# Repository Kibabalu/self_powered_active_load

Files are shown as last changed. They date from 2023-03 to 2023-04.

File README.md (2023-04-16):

# self_powered_active_load

Self powered active load based on the legendary LM10 Operational Amplifier and Voltage Reference IC originally designed by Bob Widlar.

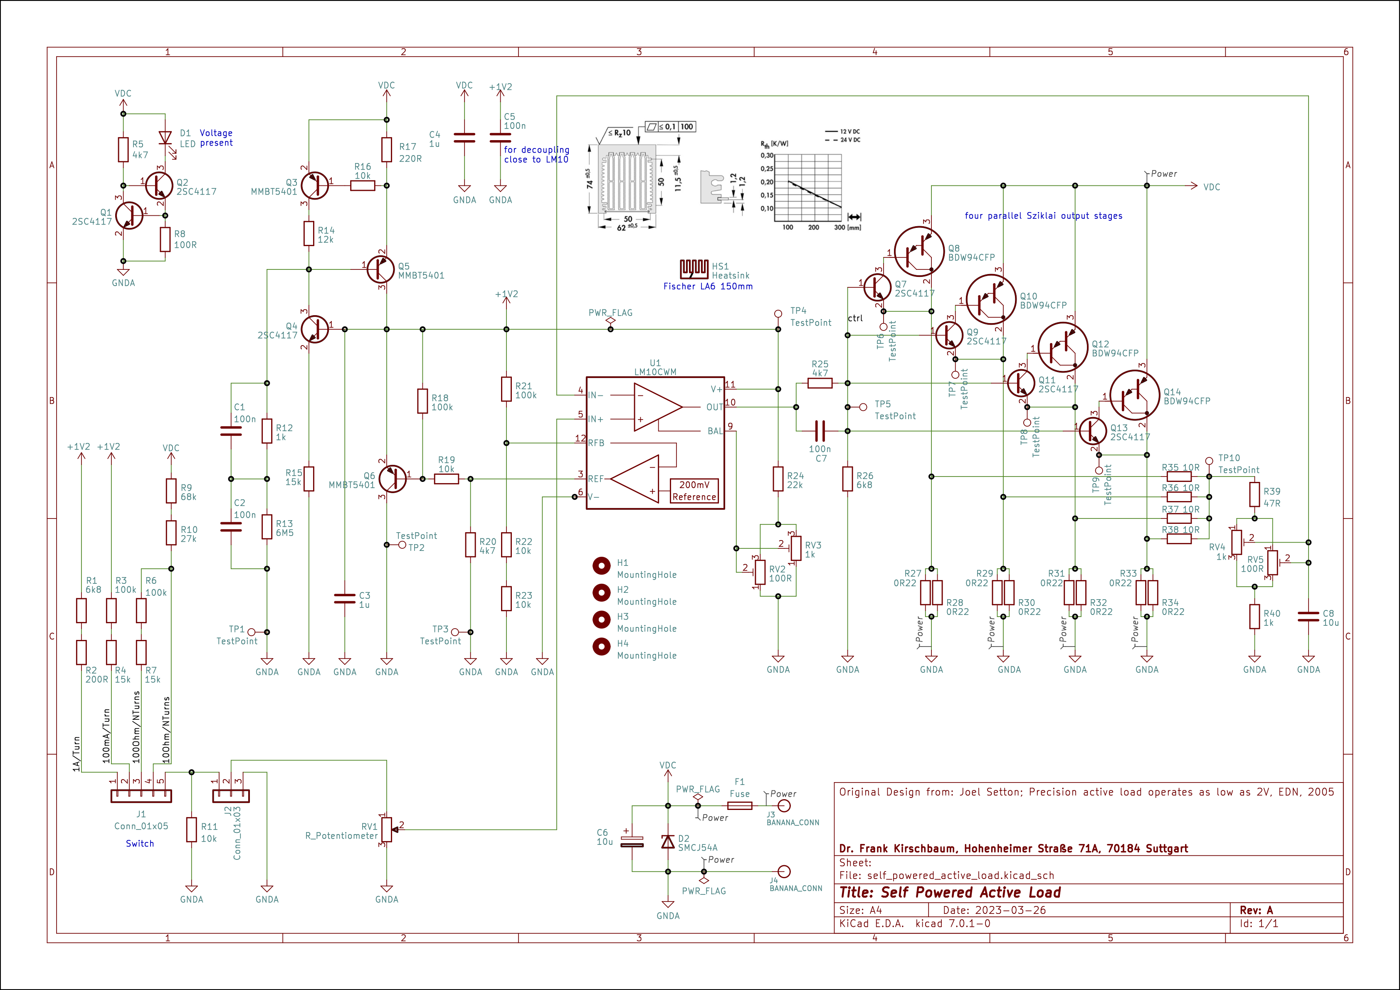
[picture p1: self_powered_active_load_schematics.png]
Schematics


Independently of the applied voltage, the circuit composed by the transistors Q3, Q4, Q5, and Q6 generates a constant voltage of 1.2V to supply the LM10 controlled by the LM10 reference buffer itself. Thus, it is controlling its own supply voltage. Q3, Q4, and Q5 are composing a current mirror and Q6 is the final control element. This works down to an applied voltage of 2V. The transistors Q1 and Q2 are forming a constant current source to drive a power-on-LED independently from the applied voltage.

The main function of the circuit, the load current control, is done by the remaining precision operational amplifier. Four Sziklai-like output stages functions as final control elements for the current load.

For the heat to be dissipated, an appropriate heat sink is needed. Here the sink LA 6 from Fischer Elektronik with a length of 150mm is used. The sink can be optionally equipped with a fan. This can increases the maximum allowed power a lot.

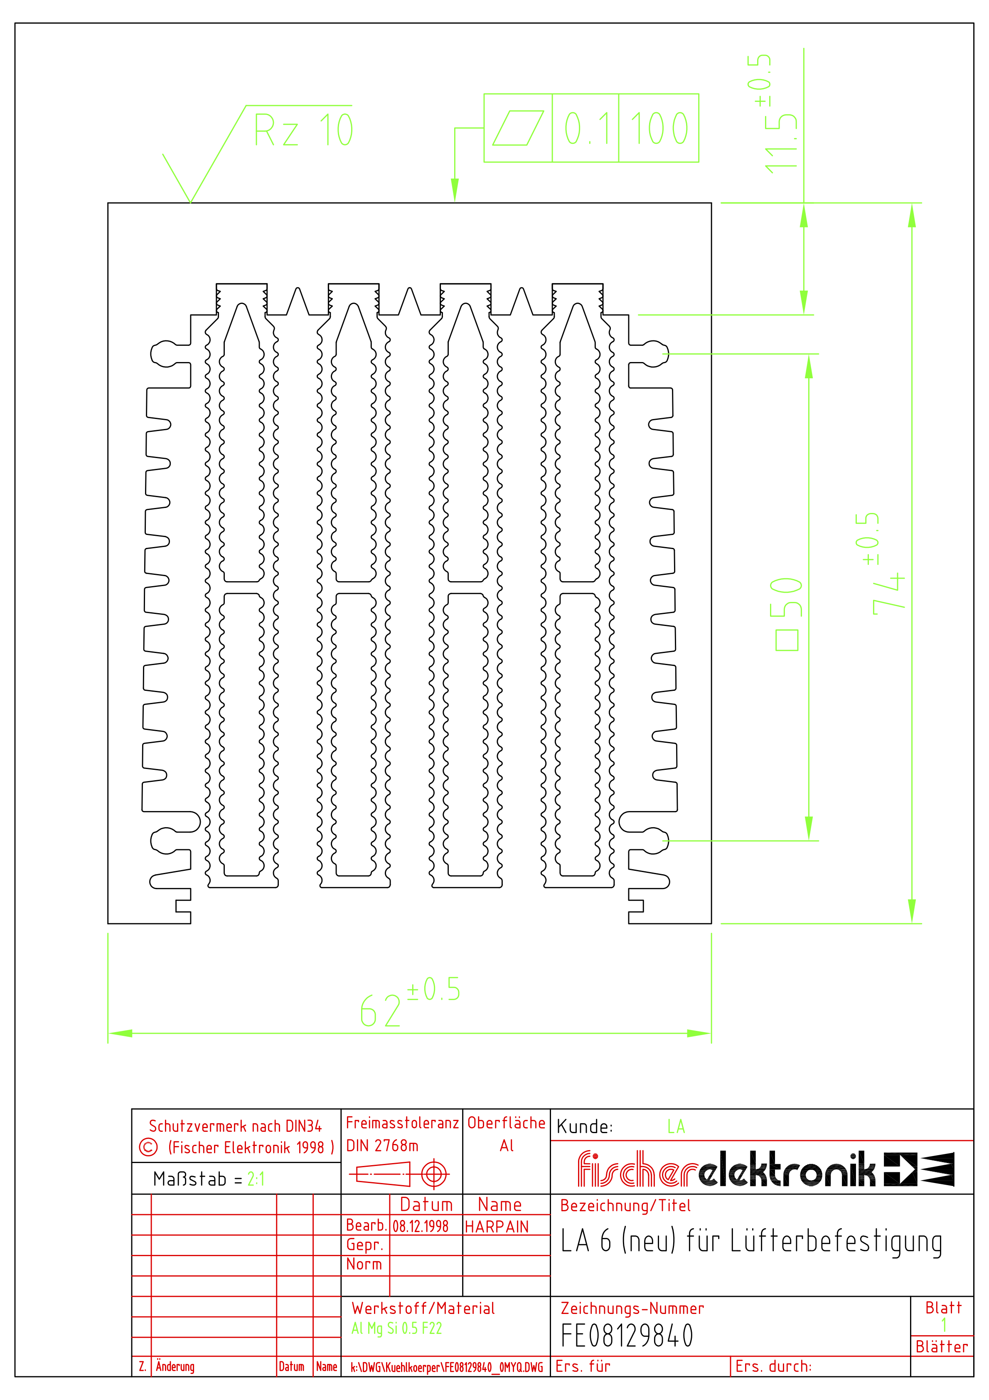
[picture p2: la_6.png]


The specs are roughly
- Voltage: It starts down at 2V and goes up to 60V. Technically the upper border goes up to 100V due to the chosen transistor BDW93CFP for the output stages. **But it's not recommended to leave the safe area of safety-low voltages**, in particular for amateurs. Stay always inside the field covered up by your knowledge and expierences!
- Max current: Each of the four Sziklai-like output stages with their shunt resistors can stand approx. 2.5A. Thus, overall 10A load current should be fine. For higher load currents the base circuit could be scaled by adding more output stages.
- Max power: 30W without fan / 100W with fan

Production data, including the gerber files, can be found in the subfolder _production_. Or feel free to use the source files for your own projects.

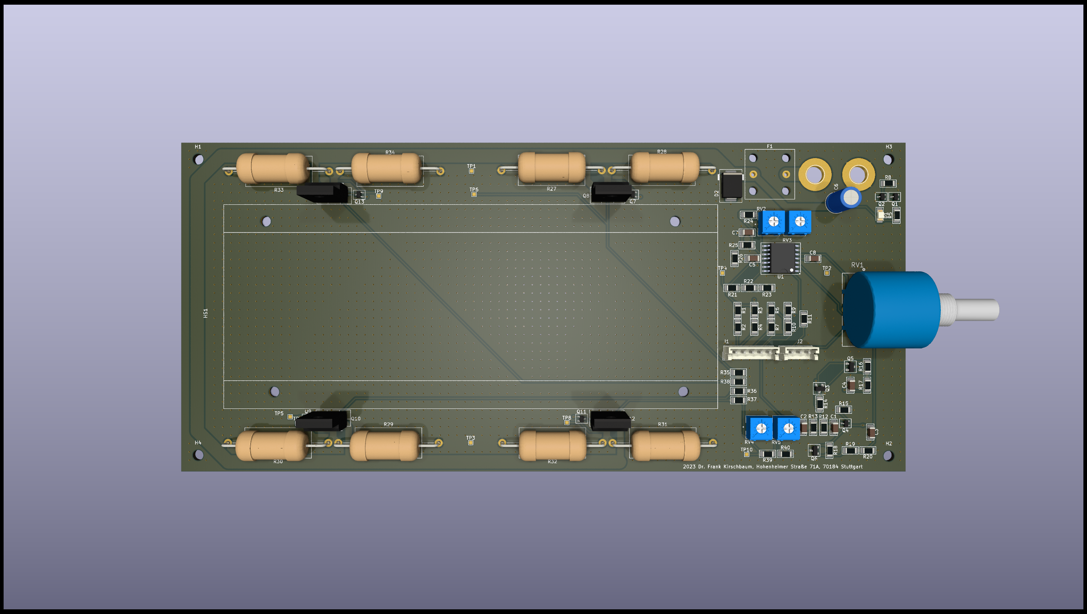
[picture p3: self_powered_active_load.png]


The Circuit is mainly adopted from the source: Joel Setton; _Precision active load operates as low as 2V_, EDN, 2005. There's also a commercial version based on the same original circuit available: The TekBox TBOH02 self powered load.

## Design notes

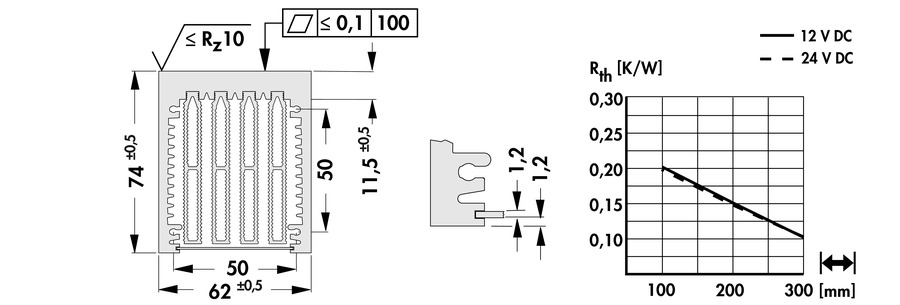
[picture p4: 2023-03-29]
la6.jpg

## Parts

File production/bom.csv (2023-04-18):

Designator | Footprint | Quantity | Value | LCSC Part #
C1, C2, C5, C7 | 1206 | 4 | 100n
C3, C4 | 1206 | 2 | 1u
C6 | C_Radial_D6.3mm_H11.0mm_P2.50mm | 1 | 10u
C8 | 1206 | 1 | 10u
D1 | 1206 | 1 | LED
D2 | D_SMC | 1 | SMCJ54A
F1 | Fuseholder_Cylinder-5x20mm_EATON_HBV_Vertical_Closed | 1 | Fuse
H1, H2, H3, H4 | MountingHole_3.2mm_M3_DIN965 | 4 | MountingHole
HS1 | Fischer_Heatsink_LA6_150 | 1 | Heatsink
J1 | JST_EH_B5B-EH-A_1x05_P2.50mm_Vertical | 1 | Conn_01x05
J2 | JST_EH_B3B-EH-A_1x03_P2.50mm_Vertical | 1 | Conn_01x03
J3, J4 | BANANA_CONN | 2 | BANANA_CONN
Q1, Q11, Q13, Q2, Q4, Q7, Q9 | SOT-323_SC-70 | 7 | 2SC4117
Q10, Q12, Q14, Q8 | TO-220F-3_Vertical_BCE | 4 | BDW94CFP
Q3, Q5, Q6 | SOT-23 | 3 | MMBT5401
R1, R26 | 1206 | 2 | 6k8
R10 | 1206 | 1 | 27k
R11, R16, R19, R22, R23 | 1206 | 5 | 10k
R12, R40 | 1206 | 2 | 1k
R13 | 1206 | 1 | 6M5
R14 | 1206 | 1 | 12k
R15, R4, R7 | 1206 | 3 | 15k
R17 | 1206 | 1 | 220R
R18, R21, R3, R6 | 1206 | 4 | 100k
R2 | 1206 | 1 | 200R
R20, R25, R5 | 1206 | 3 | 4k7
R24 | 1206 | 1 | 22k
R27, R29, R31, R33 | R_Axial_DIN0922_L20.0mm_D9.0mm_P30.48mm_Horizontal | 4 | DNP
R28, R30, R32, R34 | R_Axial_DIN0922_L20.0mm_D9.0mm_P30.48mm_Horizontal | 4 | 0R22
R35, R36, R37, R38 | 1206 | 4 | 10R
R39 | 1206 | 1 | 47R
R8 | 1206 | 1 | 100R
R9 | 1206 | 1 | 68k
RV1 | TRIM_3590S-2-103L | 1 | R_Potentiometer
RV2, RV5 | TRIM_3362P-1-102LF | 2 | 100R
RV3, RV4 | TRIM_3362P-1-102LF | 2 | 1k
TP1, TP10, TP2, TP3, TP4, TP5, TP6, TP7, TP8, TP9 | TestPoint_Pad_1.0x1.0mm | 10 | TestPoint
U1 | SOIC-14W_7.5x9mm_P1.27mm | 1 | LM10CWM

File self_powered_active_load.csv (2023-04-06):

Source: | /Users/frankkirschbaum/Documents/KiCad/projects/self_powered_active_load/self_powered_active_load.kicad_sch
Date: | 2023 April 04, Tuesday 20:44:26
Tool: | Eeschema 7.0.1-0
Generator: | /Applications/KiCad/KiCad.app/Contents/SharedSupport/plugins/bom_csv_grouped_by_value.py
Component Count: | 90
Collated Components:
Item | Qty | Reference(s) | Value | LibPart | Footprint | Datasheet | DNP | Sim.Device | Sim.Enable | Sim.Library | Sim.Name | Sim.Params | Sim.Pins | Sim.Type
1 | 1 | C1 | 100n | Device:C | Capacitor_SMD_AKL:C_1206_3216Metric_Pad1.42x1.75mm_HandSolder | ~
2 | 3 | C2, C5, C7 | 100n | Device:C | Capacitor_SMD_AKL:C_1206_3216Metric_Pad1.33x1.80mm_HandSolder | ~
3 | 2 | C3, C4 | 1u | Device:C | Capacitor_SMD_AKL:C_1206_3216Metric_Pad1.33x1.80mm_HandSolder | ~ |  | C |  |  |  |  | 1=+ 2=-
4 | 1 | C6 | 10u | Capacitor_AKL:CP_Generic | Capacitor_THT:C_Radial_D6.3mm_H11.0mm_P2.50mm | ~ |  | C |  |  |  | c="" | 1=+ 2=-
5 | 1 | C8 | 10u | Device:C | Capacitor_SMD_AKL:C_1206_3216Metric_Pad1.33x1.80mm_HandSolder | ~
6 | 1 | D1 | LED | Device:LED | LED_SMD:LED_1206_3216Metric_Pad1.42x1.75mm_HandSolder | ~ |  | D |  |  |  |  | 1=A 2=K
7 | 1 | D2 | SMCJ54A | Diode_TVS_AKL:SMCJ54A | Diode_SMD_AKL:D_SMC | https://www.tme.eu/Document/535c4da69331b5e4fe2b7f8cdcd9eb69/SMCJ_ser.pdf |  |  | 0
8 | 1 | F1 | Fuse | Device:Fuse | Fuse:Fuseholder_Cylinder-5x20mm_EATON_HBV_Vertical_Closed | ~
9 | 4 | H1, H2, H3, H4 | MountingHole | Mechanical:MountingHole | MountingHole:MountingHole_3.2mm_M3_DIN965 | ~
10 | 1 | HS1 | Heatsink | Mechanical:Heatsink | Heatsink:Fischer_Heatsink_LA6_150 | ~ |  |  | 0
11 | 1 | J1 | Conn_01x05 | Connector_Generic:Conn_01x05 | Connector_JST:JST_EH_B5B-EH-A_1x05_P2.50mm_Vertical | ~ |  |  | 0
12 | 1 | J2 | Conn_01x03 | Connector_Generic:Conn_01x03 | Connector_JST:JST_EH_B3B-EH-A_1x03_P2.50mm_Vertical | ~ |  |  | 0
13 | 2 | J3, J4 | BANANA_CONN | 5uH_LISN-eagle-import:BANANA_CONN | 5uH_LISN:BANANA_CONN
14 | 7 | Q1, Q2, Q4, Q7, Q9, Q11, Q13 | 2SC4117 | PCM_Transistor_BJT_AKL:2SC4117 | Package_TO_SOT_SMD_AKL:SOT-323_SC-70 | https://www.tme.eu/Document/999621e2b651fb09db147985687c40a5/2SC4116.pdf |  | NPN |  |  |  | bf=350 | 1=B 2=E 3=C | GUMMELPOON
15 | 3 | Q3, Q5, Q6 | MMBT5401 | PCM_Transistor_BJT_AKL:MMBT5401 | Package_TO_SOT_SMD_AKL:SOT-23 | https://www.tme.eu/Document/b3f4bd644f07863ce5f561ee60aa955c/MMBT5401LT1G.PDF |  | PNP |  |  |  |  | 1=C 2=B 3=E | VBIC
16 | 4 | Q8, Q10, Q12, Q14 | BDW94CFP | PCM_Transistor_BJT_Darlington_AKL:BDW94CFP | Package_TO_SOT_THT_AKL:TO-220F-3_Vertical_BCE | https://www.tme.eu/Document/78f266d30e553b668bab633f8dbc8045/BDW93CFP.pdf |  | SUBCKT |  | /Users/frankkirschbaum/Documents/KiCad/KiCad-Spice-Library/Models/uncategorized/spice_complete/fairch.lib | BDW94C_FC |  | 1=2 2=1 3=3
17 | 2 | R1, R26 | 6k8 | Device:R | Resistor_SMD_AKL:R_1206_3216Metric_Pad1.30x1.75mm_HandSolder | ~
18 | 1 | R2 | 200R | Device:R | Resistor_SMD_AKL:R_1206_3216Metric_Pad1.30x1.75mm_HandSolder | ~
19 | 4 | R3, R6, R18, R21 | 100k | Device:R | Resistor_SMD_AKL:R_1206_3216Metric_Pad1.30x1.75mm_HandSolder | ~
20 | 3 | R4, R7, R15 | 15k | Device:R | Resistor_SMD_AKL:R_1206_3216Metric_Pad1.30x1.75mm_HandSolder | ~
21 | 3 | R5, R20, R25 | 4k7 | Device:R | Resistor_SMD_AKL:R_1206_3216Metric_Pad1.30x1.75mm_HandSolder | ~
22 | 1 | R8 | 100R | Device:R | Resistor_SMD_AKL:R_1206_3216Metric_Pad1.30x1.75mm_HandSolder | ~
23 | 1 | R9 | 68k | Device:R | Resistor_SMD_AKL:R_1206_3216Metric_Pad1.30x1.75mm_HandSolder | ~
24 | 1 | R10 | 27k | Device:R | Resistor_SMD_AKL:R_1206_3216Metric_Pad1.30x1.75mm_HandSolder | ~
25 | 5 | R11, R16, R19, R22, R23 | 10k | Device:R | Resistor_SMD_AKL:R_1206_3216Metric_Pad1.30x1.75mm_HandSolder | ~
26 | 2 | R12, R40 | 1k | Device:R | Resistor_SMD_AKL:R_1206_3216Metric_Pad1.30x1.75mm_HandSolder | ~
27 | 1 | R13 | 6M5 | Device:R | Resistor_SMD_AKL:R_1206_3216Metric_Pad1.30x1.75mm_HandSolder | ~
28 | 1 | R14 | 12k | Device:R | Resistor_SMD_AKL:R_1206_3216Metric_Pad1.30x1.75mm_HandSolder | ~
29 | 1 | R17 | 220R | Device:R | Resistor_SMD_AKL:R_1206_3216Metric_Pad1.30x1.75mm_HandSolder | ~ |  | R |  |  |  | r=R | 1=+ 2=- | =
30 | 1 | R24 | 22k | Device:R | Resistor_SMD_AKL:R_1206_3216Metric_Pad1.30x1.75mm_HandSolder | ~
31 | 8 | R27, R28, R29, R30, R31, R32, R33, R34 | 0R22 | Device:R | Resistor_THT:R_Axial_DIN0922_L20.0mm_D9.0mm_P30.48mm_Horizontal | ~
32 | 4 | R35, R36, R37, R38 | 10R | Device:R | Resistor_SMD_AKL:R_1206_3216Metric_Pad1.30x1.75mm_HandSolder | ~ |  | R |  |  |  |  | 1=+ 2=-
33 | 1 | R39 | 47R | Device:R | Resistor_SMD_AKL:R_1206_3216Metric_Pad1.30x1.75mm_HandSolder | ~
34 | 1 | RV1 | R_Potentiometer | Device:R_Potentiometer | 3590S-2-103L:TRIM_3590S-2-103L | ~ |  | R |  |  |  | r="" | 1=r0 2=wiper 3=r1 | POT
35 | 2 | RV2, RV5 | 100R | Device:R_Potentiometer_Trim | 3362P-1-102LF:TRIM_3362P-1-102LF | ~ |  | R |  |  |  | r="" | 1=r0 2=wiper 3=r1 | POT
36 | 2 | RV3, RV4 | 1k | Device:R_Potentiometer_Trim | 3362P-1-102LF:TRIM_3362P-1-102LF | ~ |  | R |  |  |  | r="" | 1=r0 2=wiper 3=r1 | POT
37 | 10 | TP1, TP2, TP3, TP4, TP5, TP6, TP7, TP8, TP9, TP10 | TestPoint | Connector:TestPoint | TestPoint:TestPoint_Pad_1.0x1.0mm | ~
38 | 1 | U1 | LM10CWM | Amplifier_Operational_AKL:LM10CWM | Package_SO_AKL:SOIC-14W_7.5x9mm_P1.27mm | https://www.ti.com/lit/ds/symlink/lm10.pdf |  | SUBCKT |  | /Users/frankkirschbaum/Documents/KiCad/KiCad-Spice-Library/Models/uncategorized/Bordodynovs Electronics Lib/sub/LM10Cx.lib | LM10Cx |  | 3=7 4=4 5=6 6=1 9=IN+ 10=IN- 11=V+ 12=V-

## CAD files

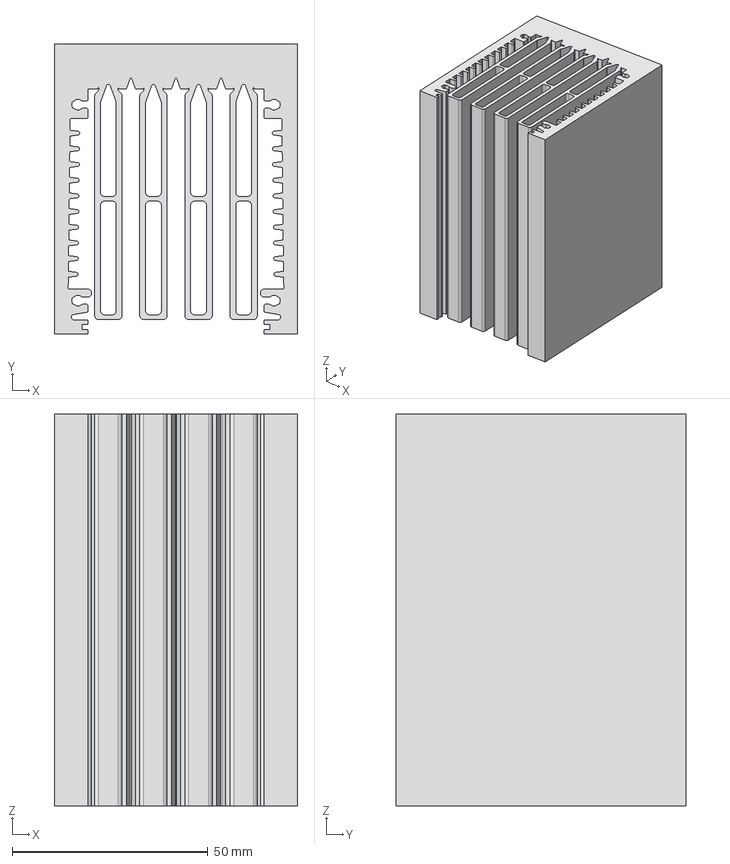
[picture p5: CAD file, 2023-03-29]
la_6.stp
62.0 x 74.0 x 100.0 mm

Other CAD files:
la_6.dxf
la_6.igs

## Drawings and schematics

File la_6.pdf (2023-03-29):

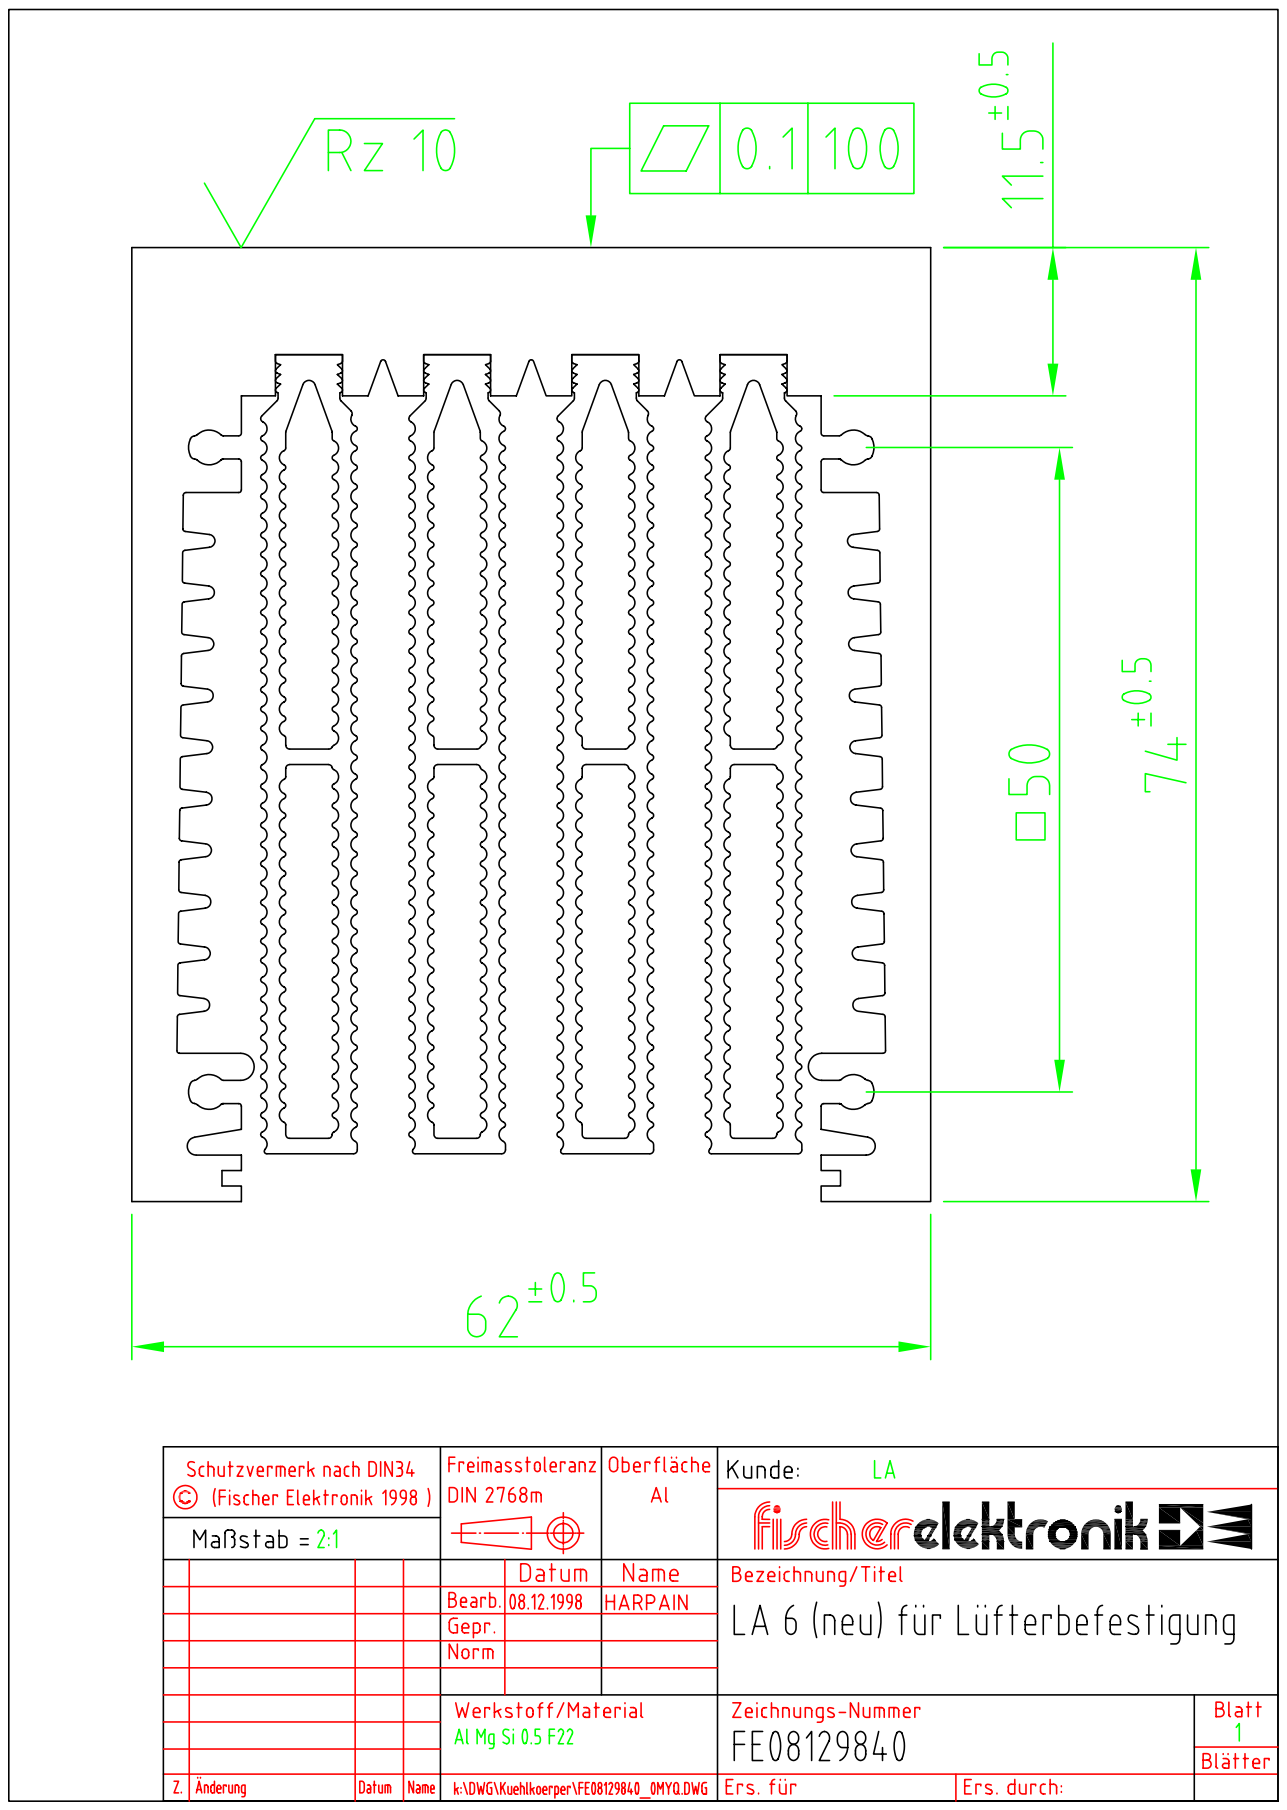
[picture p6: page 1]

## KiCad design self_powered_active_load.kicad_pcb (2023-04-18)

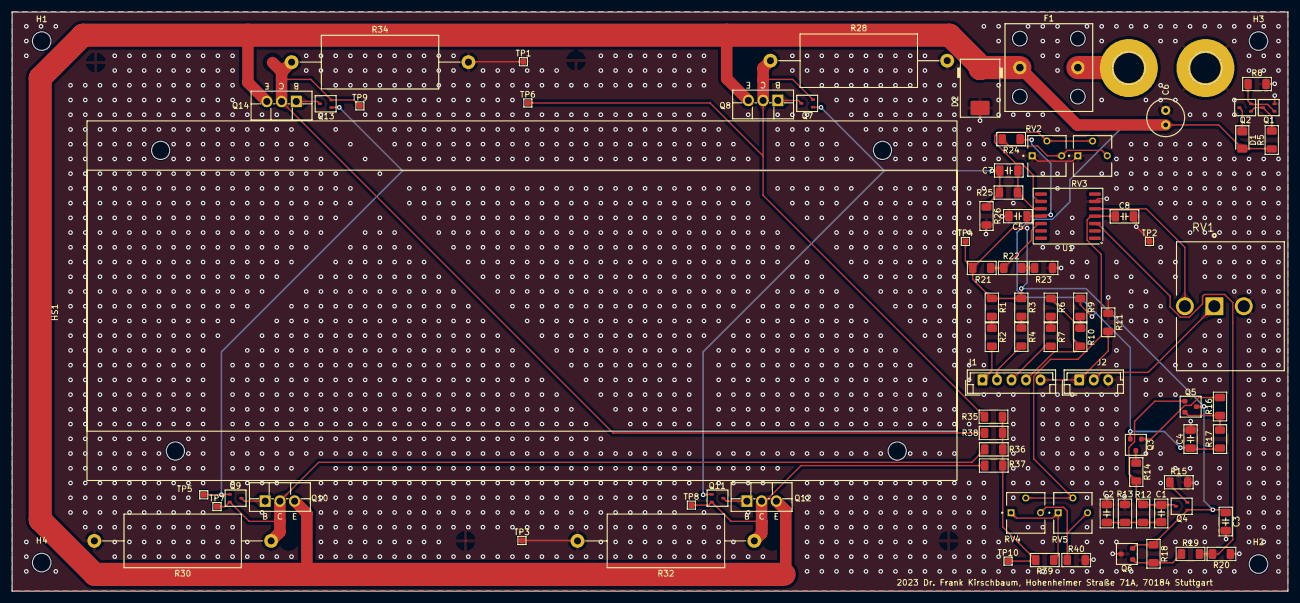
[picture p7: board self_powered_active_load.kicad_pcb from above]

Board: 2 copper layers, 220.0 x 99.8 mm, 86 parts (0 on the bottom side), 44 nets.

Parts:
C1: 100n; C_1206_3216Metric_Pad1.42x1.75mm_HandSolder
C2, C5, C7: 100n; C_1206_3216Metric_Pad1.33x1.80mm_HandSolder
C3, C4: 1u; C_1206_3216Metric_Pad1.33x1.80mm_HandSolder
C6: 10u; C_Radial_D6.3mm_H11.0mm_P2.50mm
C8: 10u; C_1206_3216Metric_Pad1.33x1.80mm_HandSolder
D1: LED; LED_1206_3216Metric_Pad1.42x1.75mm_HandSolder
D2: SMCJ54A; D_SMC
F1: Fuse; Fuseholder_Cylinder-5x20mm_EATON_HBV_Vertical_Closed
H1, H2, H3, H4: MountingHole; MountingHole_3.2mm_M3_DIN965
HS1: Heatsink; Fischer_Heatsink_LA6_150
J1: Conn_01x05; JST_EH_B5B-EH-A_1x05_P2.50mm_Vertical
J2: Conn_01x03; JST_EH_B3B-EH-A_1x03_P2.50mm_Vertical
J3, J4: BANANA_CONN
Q1, Q2, Q4, Q7, Q9, Q11, Q13: 2SC4117; SOT-323_SC-70
Q3, Q5, Q6: MMBT5401; SOT-23
Q8, Q10, Q12, Q14: BDW94CFP; TO-220F-3_Vertical_BCE
R1, R26: 6k8; R_1206_3216Metric_Pad1.30x1.75mm_HandSolder
R2: 200R; R_1206_3216Metric_Pad1.30x1.75mm_HandSolder
R3, R6, R18, R21: 100k; R_1206_3216Metric_Pad1.30x1.75mm_HandSolder
R4, R7, R15: 15k; R_1206_3216Metric_Pad1.30x1.75mm_HandSolder
R5, R20, R25: 4k7; R_1206_3216Metric_Pad1.30x1.75mm_HandSolder
R8: 100R; R_1206_3216Metric_Pad1.30x1.75mm_HandSolder
R9: 68k; R_1206_3216Metric_Pad1.30x1.75mm_HandSolder
R10: 27k; R_1206_3216Metric_Pad1.30x1.75mm_HandSolder
R11, R16, R19, R22, R23: 10k; R_1206_3216Metric_Pad1.30x1.75mm_HandSolder
R12, R40: 1k; R_1206_3216Metric_Pad1.30x1.75mm_HandSolder
R13: 6M5; R_1206_3216Metric_Pad1.30x1.75mm_HandSolder
R14: 12k; R_1206_3216Metric_Pad1.30x1.75mm_HandSolder
R17: 220R; R_1206_3216Metric_Pad1.30x1.75mm_HandSolder
R24: 22k; R_1206_3216Metric_Pad1.30x1.75mm_HandSolder
R28, R30, R32, R34: 0R22; R_Axial_DIN0922_L20.0mm_D9.0mm_P30.48mm_Horizontal
R35, R36, R37, R38: 10R; R_1206_3216Metric_Pad1.30x1.75mm_HandSolder
R39: 47R; R_1206_3216Metric_Pad1.30x1.75mm_HandSolder
RV1: R_Potentiometer; TRIM_3590S-2-103L
RV2, RV5: 100R; TRIM_3362P-1-102LF
RV3, RV4: 1k; TRIM_3362P-1-102LF
TP1, TP2, TP3, TP4, TP5, TP6, TP7, TP8, TP9, TP10: TestPoint; TestPoint_Pad_1.0x1.0mm
U1: LM10CWM; SOIC-14W_7.5x9mm_P1.27mm

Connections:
+1V2: C3.1, C5.1, Q4.1 (B), Q5.3 (C), Q6.2 (E), R1.1, R3.1, R18.1, R21.1, R24.1, TP4.1, U1.11 (V+)
/1A/Turn: J1.1, R2.2
/10Ohm/NTurns: J1.4, R6.1, R10.2
/100Ohm/NTurns: J1.3, R7.2
/100mA/Turn: J1.2, R4.2
/ctrl: C7.2, Q7.1 (B), Q9.1 (B), Q11.1 (B), Q13.1 (B), R25.2, R26.1, TP5.1
GNDA: C2.2, C3.2, C4.2, C5.2, C6.2, C8.2, D2.2 (A), J2.3, J4.P$1 (1), Q1.2 (E), Q6.3 (C), R8.2, R11.1, R13.2, R15.2, R20.1, R23.2, R26.2, R28.2, R30.2, R32.2, R34.2, R40.2, RV1.3, RV2.1, RV3.1, TP1.1, TP2.1, TP3.1, U1.6 (V-)
unnamed: C1.2, C2.1, R12.2, R13.1
unnamed: D1.1 (K), Q2.3 (C)
unnamed: J1.5, J2.1, R11.2
unnamed: J2.2, RV1.1
unnamed: F1.2, J3.P$1 (1)
unnamed: Q1.1 (B), Q2.2 (E), R8.1
unnamed: Q1.3 (C), Q2.1 (B), R5.2
unnamed: Q3.1 (B), R16.2
unnamed: Q3.3 (C), R14.1
unnamed: C1.1, Q4.3 (C), Q5.1 (B), R12.1, R14.2
unnamed: Q4.2 (E), R15.1
unnamed: Q5.2 (E), R16.1, R17.2
unnamed: Q6.1 (B), R18.2, R19.1
unnamed: Q7.3 (C), Q8.1 (B)
unnamed: Q7.2 (E), Q8.2 (C), R28.1, R35.1, TP6.1
unnamed: Q9.3 (C), Q10.1 (B)
unnamed: Q9.2 (E), Q10.2 (C), R30.1, R36.1, TP7.1
unnamed: Q11.3 (C), Q12.1 (B)
unnamed: Q11.2 (E), Q12.2 (C), R32.1, R37.1, TP8.1
unnamed: Q13.3 (C), Q14.1 (B)
unnamed: Q13.2 (E), Q14.2 (C), R34.1, R38.1, TP9.1
unnamed: R1.2, R2.1
unnamed: R3.2, R4.1
unnamed: R6.2, R7.1
unnamed: R9.2, R10.1
unnamed: R22.2, R23.1
unnamed: R24.2, RV2.3, RV3.3
unnamed: R35.2, R36.2, R37.2, R38.2, R39.2, TP10.1
unnamed: R39.1, RV4.1, RV5.1
unnamed: R40.1, RV4.3, RV5.3
unnamed: RV2.2, RV3.2, U1.9 (BAL)
unnamed: RV1.2, U1.5 (IN+)
unnamed: C8.1, RV4.2, RV5.2, U1.4 (IN-)
unnamed: C7.1, R25.1, U1.10 (OUT)
unnamed: R19.2, R20.2, U1.3 (REF)
unnamed: R21.2, R22.1, U1.12 (RFB)
VDC: C4.1, C6.1, D1.2 (A), D2.1 (K), F1.1, Q3.2 (E), Q8.3 (E), Q10.3 (E), Q12.3 (E), Q14.3 (E), R5.1, R9.1, R17.1

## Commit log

2023-03-29 1st commit
    [la_6.dxf, la_6.igs, la_6.stp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]
2023-04-01 routing 1st version
    [self_powered_active_load.kicad_pcb]
2023-04-01 documentation schematics
2023-04-04 PCB picture added
2023-04-04 test points added
    [self_powered_active_load.kicad_pcb, self_powered_active_load.kicad_sch]
2023-04-04 some more documentation
    [bom.csv, designators.csv, positions.csv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]
2023-04-06 upper side floated with GND
    [self_powered_active_load.csv, self_powered_active_load.kicad_pcb]
2023-04-08 schematics documentation
    [self_powered_active_load.kicad_sch]
2023-04-09 Name added on PCB
    [self_powered_active_load.kicad_pcb, self_powered_active_load.kicad_sch]
2023-04-09 Name on PCB edited
    [self_powered_active_load.kicad_pcb]
2023-04-09 via stitching added
    [self_powered_active_load.kicad_pcb]
2023-04-09 schematics print
2023-04-16 Ref A2
    [self_powered_active_load.kicad_pcb, self_powered_active_load.kicad_sch]
2023-04-17 error fixed shunts
    [self_powered_active_load.kicad_pcb, self_powered_active_load.kicad_sch]
2023-04-18 error removed shunt in PCB
    [bom.csv, self_powered_active_load.kicad_pcb, self_powered_active_load.kicad_sch]
